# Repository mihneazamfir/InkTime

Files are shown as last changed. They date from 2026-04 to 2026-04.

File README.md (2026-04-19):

# InkTime — Open Source E-Paper Smartwatch

> Smartwatch open-source cu display e-paper, bazat pe nRF52840 SoC cu Bluetooth 5.0.

---

## Block Diagram

```
                    ┌─────────────────────────────────────────────────┐
                    │               nRF52840 (MCU)                    │
                    │          ARM Cortex-M4F @ 64MHz                 │
                    │        1MB Flash | 256KB RAM | BLE 5.0          │
                    └──┬──────────┬──────────┬──────────┬─────────────┘
                       │ SPI      │ I²C      │ GPIO     │ SWD
          ┌────────────┘          │          │          └──────────────┐
          ▼                       ▼          ▼                         ▼
  E-Paper Display         ┌──────────┐   Butoane (x3)           Debug Header
  WSH-12561 1.54"         │ I²C Bus  │   SW_UP / SW_ENT          (SWO/SWDIO
  200x200px               │ SCL/SDA  │   SW_DN                    /SWDCLK)
                          └──┬───┬───┘
                             │   │
                    ┌────────┘   └────────┐
                    ▼                     ▼
                BMA423               MAX17048
               (IMU/Step)           (Fuel Gauge)
                + DRV2605             + BQ25180
               (Haptic)              (Charger)

                    ┌──────────────────────────────────────┐
                    │          Power Management            │
                    │  USB-C ──► BQ25180 ──► AKY0106      │
                    │          (Charger)   (LiPo 400mAh)  │
                    │              │                       │
                    │              ▼                       │
                    │      RT6160AWSC (DC/DC)              │
                    │      VIN→3.3V (TP_3V3)               │
                    │      + EPD_3V3 rail separat          │
                    └──────────────────────────────────────┘
```

---

## Bill of Materials (BOM)

| Ref | Componentă | Package | Descriere | JLC Parts | Datasheet |
|-----|---|---|---|---|---|
| U1 | nRF52840-QIAA | QFN73 | MCU BLE 5.0, ARM Cortex-M4F, 1MB Flash | [C190794](https://jlcpcb.com/parts/componentSearch?isSearch=true&searchTxt=nRF52840) | [Datasheet](https://infocenter.nordicsemi.com/pdf/nRF52840_PS_v1.7.pdf) |
| U2 | RT6160AWSC | SOT-23-6 | DC/DC Step-Down 600mA, 3.3V | [C89358](https://jlcpcb.com/parts/componentSearch?isSearch=true&searchTxt=RT6160AWSC) | [Datasheet](https://www.richtek.com/assets/product_file/RT6160A/DS6160A-02.pdf) |
| U3 | MAX17048G+T10 | SOT-23-5 | LiPo Fuel Gauge, I²C 0x36 | [C112596](https://jlcpcb.com/parts/componentSearch?isSearch=true&searchTxt=MAX17048G) | [Datasheet](https://datasheets.maximintegrated.com/en/ds/MAX17048-MAX17049.pdf) |
| U4 | BMA423 | LGA-12 | IMU 3-axis Accel + Step Counter, I²C 0x18 | [C362551](https://jlcpcb.com/parts/componentSearch?isSearch=true&searchTxt=BMA423) | [Datasheet](https://www.bosch-sensortec.com/media/boschsensortec/downloads/datasheets/bst-bma423-ds000.pdf) |
| U5 | BQ25180YBGR | DSBGA-9 | LiPo Charger 350mA, I²C 0x6B | [C2682195](https://jlcpcb.com/parts/componentSearch?isSearch=true&searchTxt=BQ25180) | [Datasheet](https://www.ti.com/lit/ds/symlink/bq25180.pdf) |
| U6 | DRV2605YFRI | DSBGA-12 | Haptic Driver I²C pentru motor vibratie | [C2678581](https://jlcpcb.com/parts/componentSearch?isSearch=true&searchTxt=DRV2605) | [Datasheet](https://www.ti.com/lit/ds/symlink/drv2605.pdf) |
| DSP1 | WSH-12561 | FPC 24-pin | E-Paper Display 1.54", 200×200px, SPI | — | [Datasheet](https://www.tme.eu/Document/0ca57a8ffbcd57b5bca53252eb9d6ec3/WSH-12561.pdf) |
| BAT1 | AKY0106 | — | LiPo 3.7V 400mAh | — | [Datasheet](https://www.tme.eu/Document/b9e12bf26ad0ba929a22ab5d58f022cd/AKY0106.pdf) |
| J1 | USB Type-C 16P | — | Conector USB-C + ESD (USBLC6-2SC6Y) | — | — |
| SW1 | SW_UP | — | Buton tactil sus | — | — |
| SW2 | SW_ENT | — | Buton tactil enter | — | — |
| SW3 | SW_DN | — | Buton tactil jos | — | — |
| X2 | Crystal 32.768kHz | — | RTC crystal low-power | — | — |
| L5 | Inductor 68µH | — | E-Paper drive circuit | — | — |
| L1 | Inductor 3.9nH | — | Matching antena BLE | — | — |

---

## Hardware Functionality

### Microcontroller — nRF52840
Inima dispozitivului este **nRF52840** (Nordic Semiconductor), ARM Cortex-M4F @ 64MHz cu Bluetooth 5.0 integrat, 1MB Flash și 256KB RAM. Antena BLE este plasată pe extensia dedicată a PCB-ului (proeminența din colțul din dreapta sus), cu cutout complet sub ea, fără plane de masă și fără trasee rutate în acea zonă. Un inductor de matching de 3.9nH (L1) asigură adaptarea de impedanță a antenei.

### Display E-Paper — WSH-12561
- **Interfață:** SPI (P0.02=SCK, P0.03=MOSI, P0.04=EPD_CS, P0.05=EPD_DC) + GPIO (P0.06=EPD_RST, EPD_BUSY)
- **Rezoluție:** 200×200 px, 1.54 inch, monocrom bistabil
- **Alimentare:** EPD_3V3 — rail separat generat de DC/DC
- **Circuit drive dedicat:** bobină 68µH + diode Schottky MBR0530 + tranzistor SI1308EDL-T1-GE3
- **Consum:** ~0 µA standby (bistabil), ~26mW la refresh

### IMU — BMA423
- **Interfață:** I²C, adresă 0x18, pe bus-ul shared SDA (P0.26) / SCL (P0.27)
- **Funcții:** accelerometru 3-axis ±2–16g, pedometru hardware, wrist-tilt detection
- **IMU_INT1 / IMU_INT2** conectați la GPIO-uri nRF pentru wake-on-motion și step counter

### Fuel Gauge — MAX17048
- **Interfață:** I²C, adresă 0x36, pe bus-ul shared SDA/SCL
- **ALERT** conectat la **P0.09** pe nRF pentru notificări nivel baterie scăzut
- Algoritm ModelGauge — estimează SoC fără rezistor de sensing extern

### Battery Charger — BQ25180
- **Interfață:** I²C, adresă 0x6B, pe bus-ul shared SDA/SCL
- **PMIC_INT** conectat la **P0.11** pentru notificări charger
- Input: USB-C VBUS 5V → LiPo 3.7V, curent 350mA programabil

### DC/DC Converter — RT6160AWSC
- Step-Down sincron: VREG → 3.3V (TP_3V3), curent max 600mA, eficiență >90%
- SCL/SDA pentru ajustarea programabilă a tensiunii prin I²C
- EPD_3V3 generat ca rail separat pentru display

### Haptic Driver — DRV2605YFRI
- **Interfață:** I²C pe bus-ul shared + **HAPTIC_EN** (P0.12)
- Ieșiri JP_OP / JP_ON pentru motor vibratie LRA/ERM
- 123 efecte haptic integrate în hardware

---

## nRF52840 Pin Assignment

| Pin nRF | Net/Semnal | Componentă | Justificare |
|---|---|---|---|
| P0.00/XL1 | XL1 | Crystal 32.768kHz | RTC low-power clock |
| P0.01/XL2 | XL2 | Crystal 32.768kHz | RTC low-power clock |
| P0.02 | EPD_SCK | E-Paper SPI | SPI clock display |
| P0.03 | EPD_MOSI | E-Paper SPI | SPI data display |
| P0.04/AIN2 | EPD_CS | E-Paper | Chip select display |
| P0.05/AIN3 | EPD_DC | E-Paper | Data/Command select |
| P0.06 | EPD_RST | E-Paper | Reset hardware display |
| P0.07 | EPD_BUSY | E-Paper | Input: display ocupat |
| P0.08 | HAPTIC_EN | DRV2605 | Enable haptic driver |
| P0.09/NFC1 | ALERT | MAX17048 | Interrupt fuel gauge |
| P0.11 | PMIC_INT | BQ25180 | Interrupt charger |
| P0.12 | IMU_INT1 | BMA423 | Wake-on-motion interrupt |
| P0.13 | SW_UP | Buton sus | Input GPIO pull-up |
| P0.14 | SW_ENT | Buton enter | Input GPIO pull-up |
| P0.15 | SW_DN | Buton jos | Input GPIO pull-up |
| P0.16 | IMU_INT2 | BMA423 | Step counter interrupt |
| P0.18/RESET | RESET | — | Reset hardware MCU |
| P0.26 | SDA | I²C bus shared | Date I²C (toți senzorii) |
| P0.27 | SCL | I²C bus shared | Clock I²C |
| SWDIO | SWDIO | Debug Header | SWD programare/debug |
| SWDCLK | SWDCLK | Debug Header | SWD clock |
| SWO | SWO | Debug Header | SWD trace output |
| VBUS | VBUS | USB-C | Detecție alimentare USB |

---

## Power Budget

| Componentă | Activ | Sleep |
|---|---|---|
| nRF52840 | ~7 mA | ~2 µA (System OFF) |
| E-Paper refresh | ~7 mA (impuls ~2s) | 0 µA (bistabil) |
| BMA423 | ~150 µA | ~2 µA |
| MAX17048 | ~23 µA | ~3 µA |
| BQ25180 | ~50 µA | ~18 µA |
| DRV2605 + Motor | ~100 mA (impuls scurt) | 0 µA |
| RT6160 quiescent | ~55 µA | ~55 µA |
| **Total uz normal** | **~10–15 mA** | — |
| **Total deep sleep** | — | **~30 µA** |

**Baterie:** AKY0106 — 3.7V, 400mAh
- Uz normal (BLE activ, refresh 1/min): ~400mAh ÷ 12mA ≈ **~33 ore**
- Deep sleep (refresh rar, BLE advertising): ~400mAh ÷ 0.5mA ≈ **~33 zile**

---

## PCB Design Notes

- **Straturi:** 2 (TOP + BOTTOM), grosime PCB **1mm**
- **Plan de masă** pe ambele straturi
- **Trasee putere:** min. 0.3mm | **Trasee date:** min. 0.15mm
- **Antena nRF52840:** extensie dedicată PCB, cutout sub antenă, fără masă/trasee în zonă
- **Via stitching** între planurile de masă, în special în zona radio
- **Condensatoare decuplare 100nF** lângă pinii VDD ai fiecărui IC
- **Fără unghiuri de 90°** în trasee
- Toate componentele exclusiv pe **layer TOP**

---

## Images

### PCB 3D Render
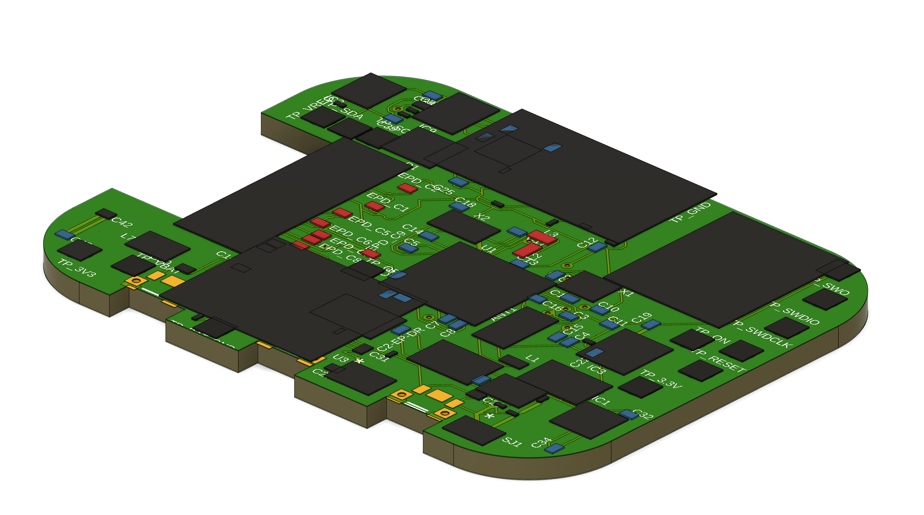
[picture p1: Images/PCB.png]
PCB 3D


### Exploded View
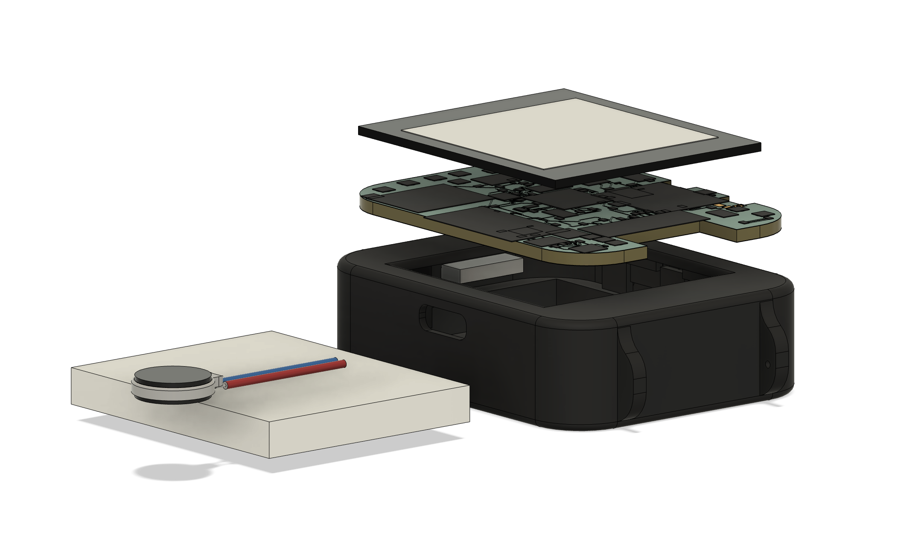
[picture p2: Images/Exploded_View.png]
Exploded View


### Device Render
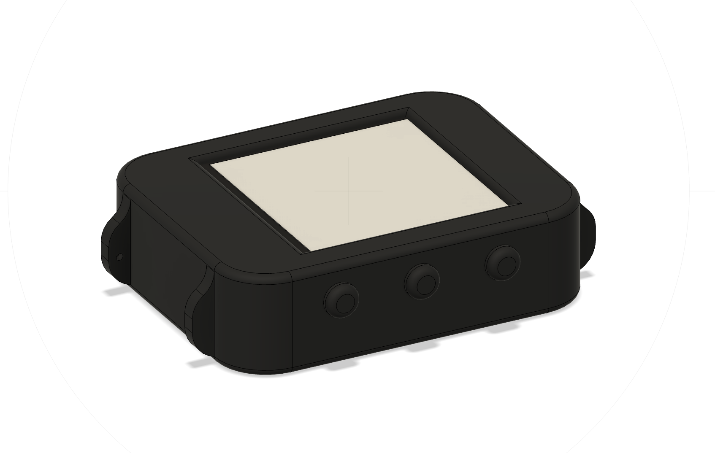
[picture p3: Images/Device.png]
Device


---

## Design Log

- **RT6160AWSC:** ales pentru eficiență la curenți mici și tensiune programabilă I²C
- **DRV2605:** 123 efecte haptic hardware fără firmware complex, suportă LRA și ERM
- **E-Paper drive circuit:** bobină 68µH + MBR0530 + SI1308EDL pentru VCOM negativ
- **Antena BLE:** extensie PCB dedicată, matching network L1=3.9nH pentru 50Ω
- **Crystal 32.768kHz:** RTC extern pentru low-power timekeeping precis
- **Bateria** conectată direct la TP_VBAT / TP_BAT_GND fără conector JST

---

## License

Distributed under the [MIT License](LICENSE).

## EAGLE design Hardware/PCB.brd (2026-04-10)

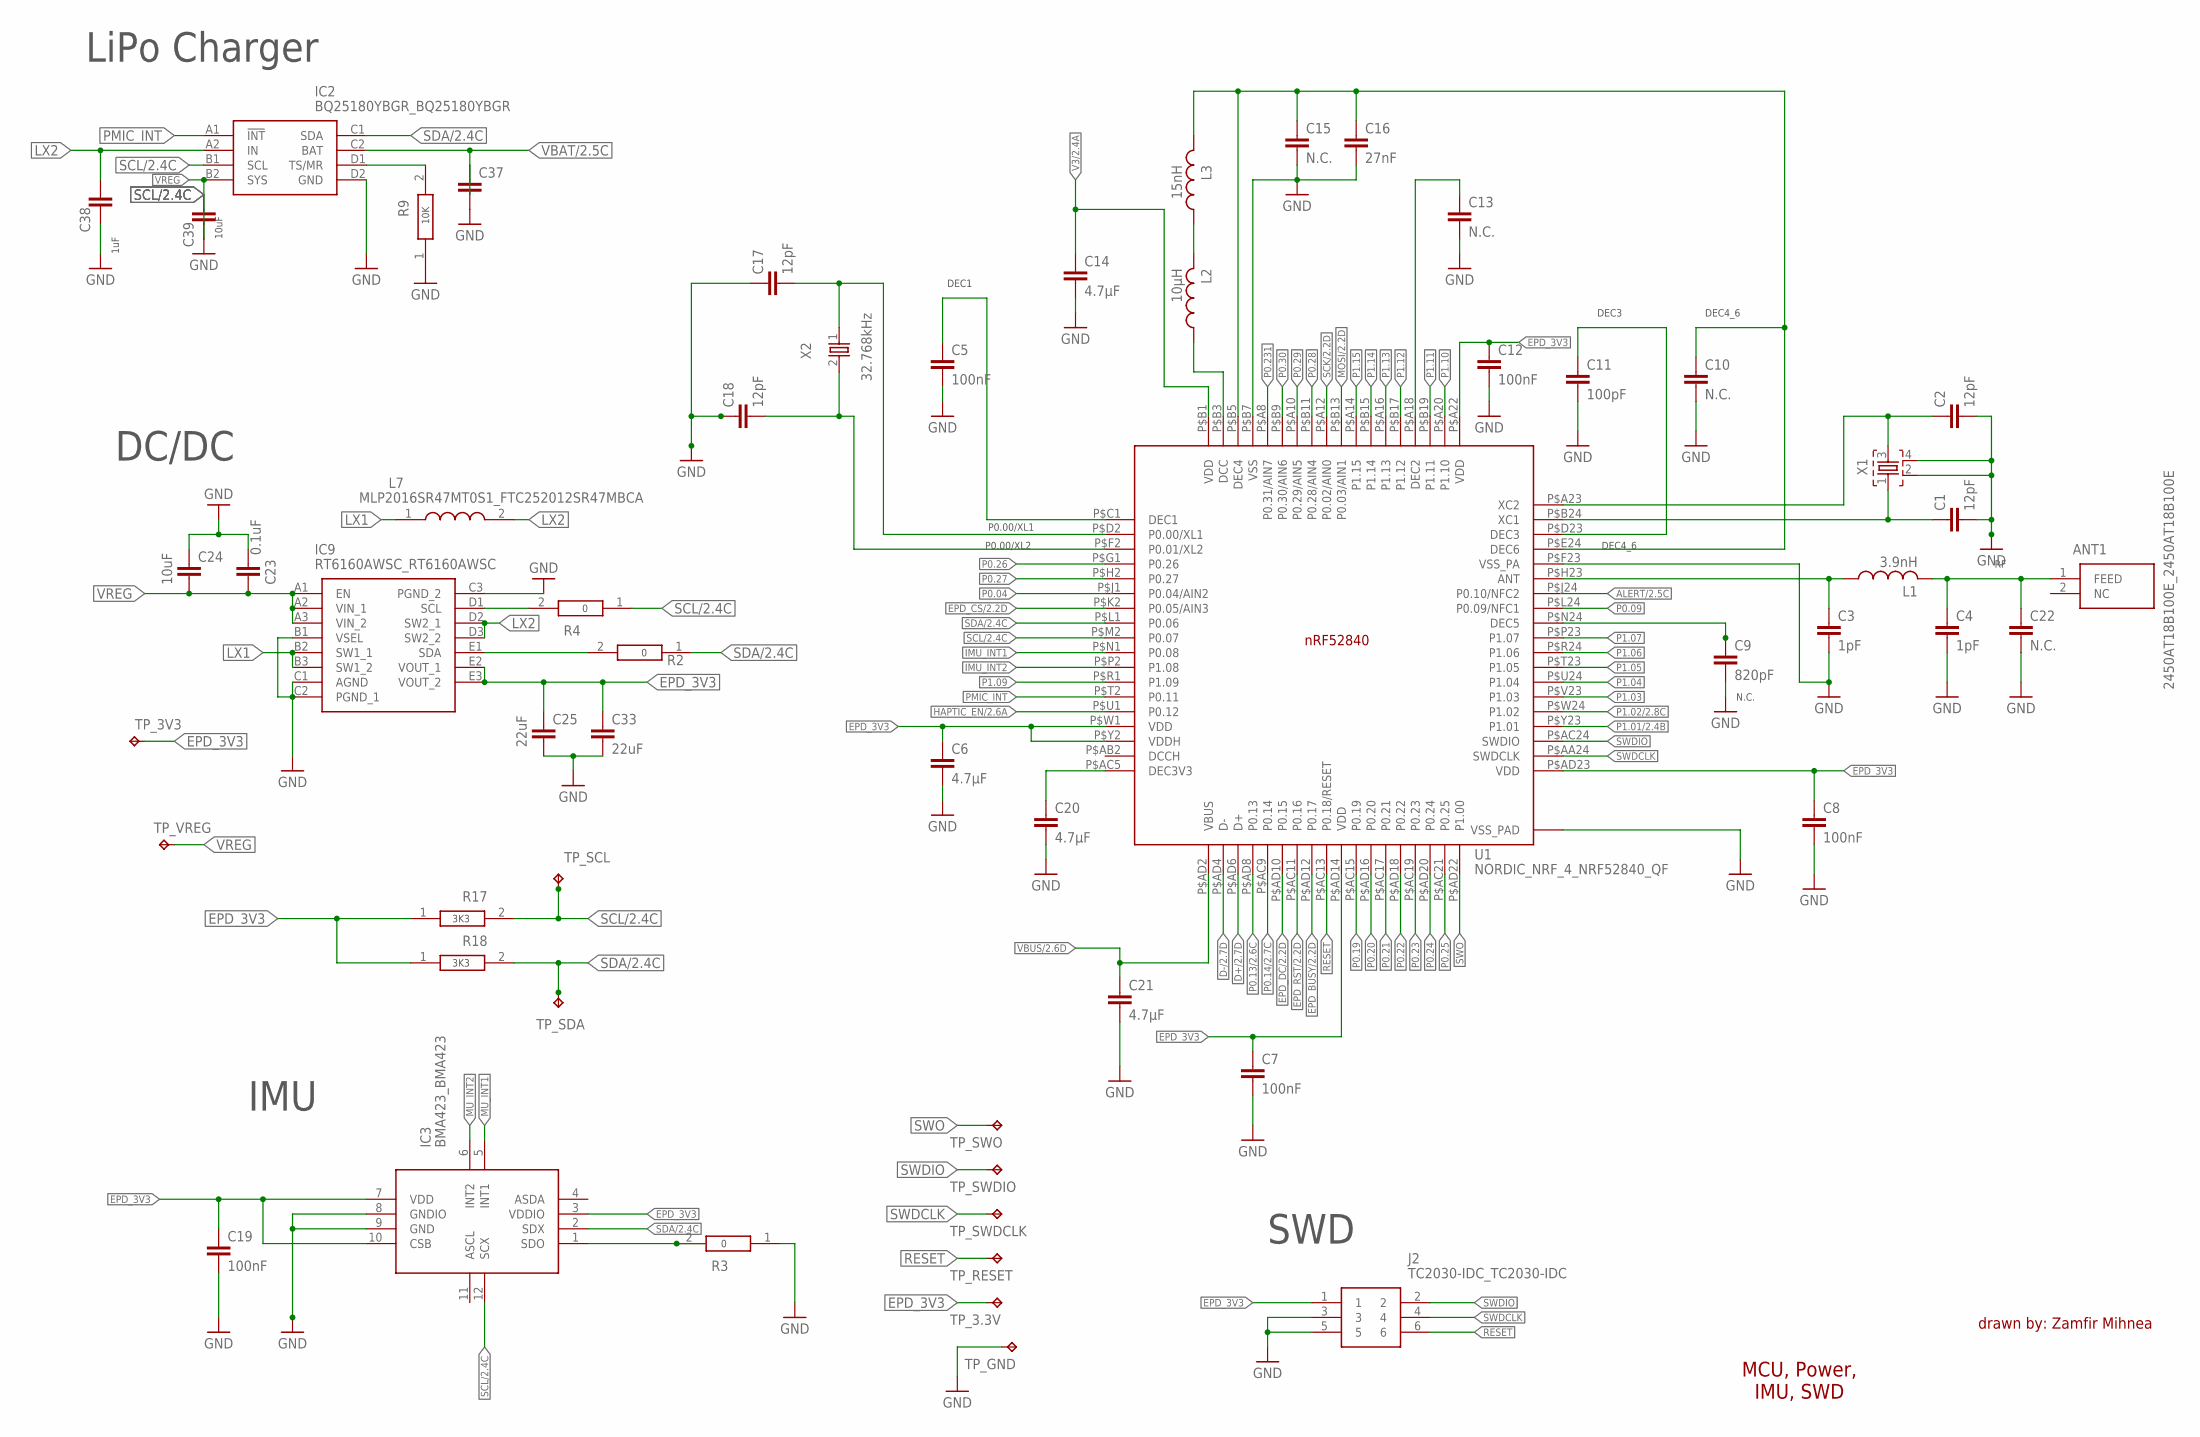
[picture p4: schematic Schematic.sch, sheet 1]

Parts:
ANT1: 2450AT18B100E_2450AT18B100E; 2450AT18B100E_ANTC3216X140N
C1, C2, C17, C18: 12pF; NORDIC_NRF_3_RESC0201_L
C3, C4: 1pF; NORDIC_NRF_3_RESC0201_L
C5, C7, C8, C12, C19: 100nF; NORDIC_NRF_3_RESC0201_L
C6, C14, C20, C21: 4.7µF; NORDIC_NRF_3_RESC0201_L
C9: 820pF; NORDIC_NRF_3_RESC0201_L
C10, C13, C15, C22: N.C.; NORDIC_NRF_3_RESC0201_L
C11: 100pF; NORDIC_NRF_3_RESC0201_L
C16: 27nF; NORDIC_NRF_3_RESC0201_L
C23: 0.1uF; NORDIC_NRF_3_RESC0201_L
C24: 10uF; NORDIC_NRF_3_RESC0201_L
C25, C33: 22uF; NORDIC_NRF_3_RESC0201_L
C37, C38, C39: NORDIC_NRF_3_CAPACITOR_0201_L; NORDIC_NRF_3_RESC0201_L
IC2: BQ25180YBGR_BQ25180YBGR; BQ25180YBGR_BGA8C40P2X4_100X155X50
IC3: BMA423_BMA423
IC9: RT6160AWSC_RT6160AWSC; RT6160AWSC_BGA15C40P3X5_140X230X60
J2: TC2030-IDC_TC2030-IDC; TC2030-IDC_TC2030IDC
L1: 3.9nH; NORDIC_NRF_2_RESC0402_L
L2: 10µH; NORDIC_NRF_2_RESC0402_L
L3: 15nH; NORDIC_NRF_2_RESC0402_L
L7: MLP2016SR47MT0S1_FTC252012SR47MBCA; MLP2016SR47MT0S1_INDC2016X100N
R2, R3, R4, R9, R17, R18: ERA-1AEB3401C_CPF0201D7K68C1; ERA-1AEB3401C_0201
TP_3.3V, TP_3V3: HECTOR_WATCH_1_TPTP20R; HECTOR_WATCH_1_TP20R
TP_GND: HECTOR_WATCH_1_TPTP20R; HECTOR_WATCH_1_TP20R
TP_RESET: HECTOR_WATCH_1_TPTP20R; HECTOR_WATCH_1_TP20R
TP_SCL: HECTOR_WATCH_1_TPTP20R; HECTOR_WATCH_1_TP20R
TP_SDA: HECTOR_WATCH_1_TPTP20R; HECTOR_WATCH_1_TP20R
TP_SWDCLK: HECTOR_WATCH_1_TPTP20R; HECTOR_WATCH_1_TP20R
TP_SWDIO: HECTOR_WATCH_1_TPTP20R; HECTOR_WATCH_1_TP20R
TP_SWO: HECTOR_WATCH_1_TPTP20R; HECTOR_WATCH_1_TP20R
TP_VREG: HECTOR_WATCH_1_TPTP20R; HECTOR_WATCH_1_TP20R
U1: NORDIC_NRF_4_NRF52840_QF; NORDIC_NRF_4_AQFN50P700X700X85_HS-74N
X1: NORDIC_NRF_XTAL_32MHZ; NORDIC_NRF_BT-XTAL_2016_N
X2: 32.768kHz; NORDIC_NRF_1_XTAL_3215_N

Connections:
GND: C3.2, C4.2, C5.2, C6.2, C7.2, C8.2, C9.2, C10.2, C11.2, C12.2, C13.2, C14.2, C15.2, C16.2, C19.2, C20.2, C21.2, C22.2, C23.1, C24.1, C25.2, C33.2, C37.2, C38.2, C39.1, C39.2, IC2.B2 (SYS), IC2.D2 (GND), IC9.B1 (VSEL), IC9.C1 (AGND), IC9.C2 (PGND_1), IC9.C3 (PGND_2), J2.3, J2.5, R3.1, R9.1, TP_GND.TP, U1.P$74 (VSS_PAD), U1.P$75 (VSS_PAD), U1.P$76 (VSS_PAD), U1.P$77 (VSS_PAD), U1.P$78 (VSS_PAD), U1.P$79 (VSS_PAD), U1.P$80 (VSS_PAD), U1.P$81 (VSS_PAD), U1.P$82 (VSS_PAD), U1.P$83 (VSS_PAD), U1.P$84 (VSS_PAD), U1.P$85 (VSS_PAD), U1.P$86 (VSS_PAD), U1.P$87 (VSS_PAD), U1.P$88 (VSS_PAD), U1.P$89 (VSS_PAD), U1.P$90 (VSS_PAD), U1.P$B7 (VSS), U1.P$F23 (VSS_PA); also elsewhere on the board
unnamed: IC2.D1 (TS/MR), R9.2
unnamed: C38.1, IC2.A2 (IN)
unnamed: C37.1, IC2.C2 (BAT)
unnamed: C23.2, C24.2, IC9.A1 (EN), IC9.A2 (VIN_1), IC9.A3 (VIN_2)
unnamed: IC9.B2 (SW1_1), IC9.B3 (SW1_2)
unnamed: IC9.D1 (SCL), R4.2
unnamed: R17.1, R18.1
unnamed: IC9.D2 (SW2_1), IC9.D3 (SW2_2)
unnamed: C25.1, C33.1, IC9.E2 (VOUT_1), IC9.E3 (VOUT_2)
unnamed: IC9.E1 (SDA), R2.2
unnamed: C19.1, IC3.7 (VDD), IC3.10 (CSB)
unnamed: IC3.8 (GNDIO), IC3.9 (GND)
unnamed: IC3.1 (SDO), R3.2
unnamed: C7.1, U1.P$AD14 (VDD)
unnamed: C21.1, U1.P$AD2 (VBUS)
unnamed: C8.1, U1.P$AD23 (VDD)
unnamed: C3.1, L1.1, U1.P$H23 (ANT)
unnamed: ANT1.1 (FEED), C4.1, C22.1, L1.2
unnamed: C10.1, C15.1, C16.1, L3.2, U1.P$B5 (DEC4), U1.P$E24 (DEC6)
unnamed: C11.1, U1.P$D23 (DEC3)
unnamed: C1.1, U1.P$B24 (XC1), X1.1
unnamed: C2.1, U1.P$A23 (XC2), X1.3
unnamed: C1.2, C2.2, X1.2, X1.4
unnamed: C12.1, U1.P$A22 (VDD)
unnamed: C13.1, U1.P$A18 (DEC2)
unnamed: L2.2, L3.1
unnamed: L2.1, U1.P$B3 (DCC)
unnamed: C20.1, U1.P$AC5 (DEC3V3)
unnamed: C6.1, U1.P$W1 (VDD), U1.P$Y2 (VDDH)
unnamed: C14.1, U1.P$B1 (VDD)
unnamed: C5.1, U1.P$C1 (DEC1)
unnamed: C17.2, U1.P$D2 (P0.00/XL1), X2.1
unnamed: C18.2, U1.P$F2 (P0.01/XL2), X2.2
SDA/2.4C: IC2.C1 (SDA)

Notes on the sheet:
LiPo Charger
10K
DC/DC
3K3
10uF
1uF
IMU
N.C.
DEC3
DEC4_6
DEC1
P0.00/XL1
P0.00/XL2
drawn by: Zamfir Mihnea
MCU, Power, IMU, SWD
SWD

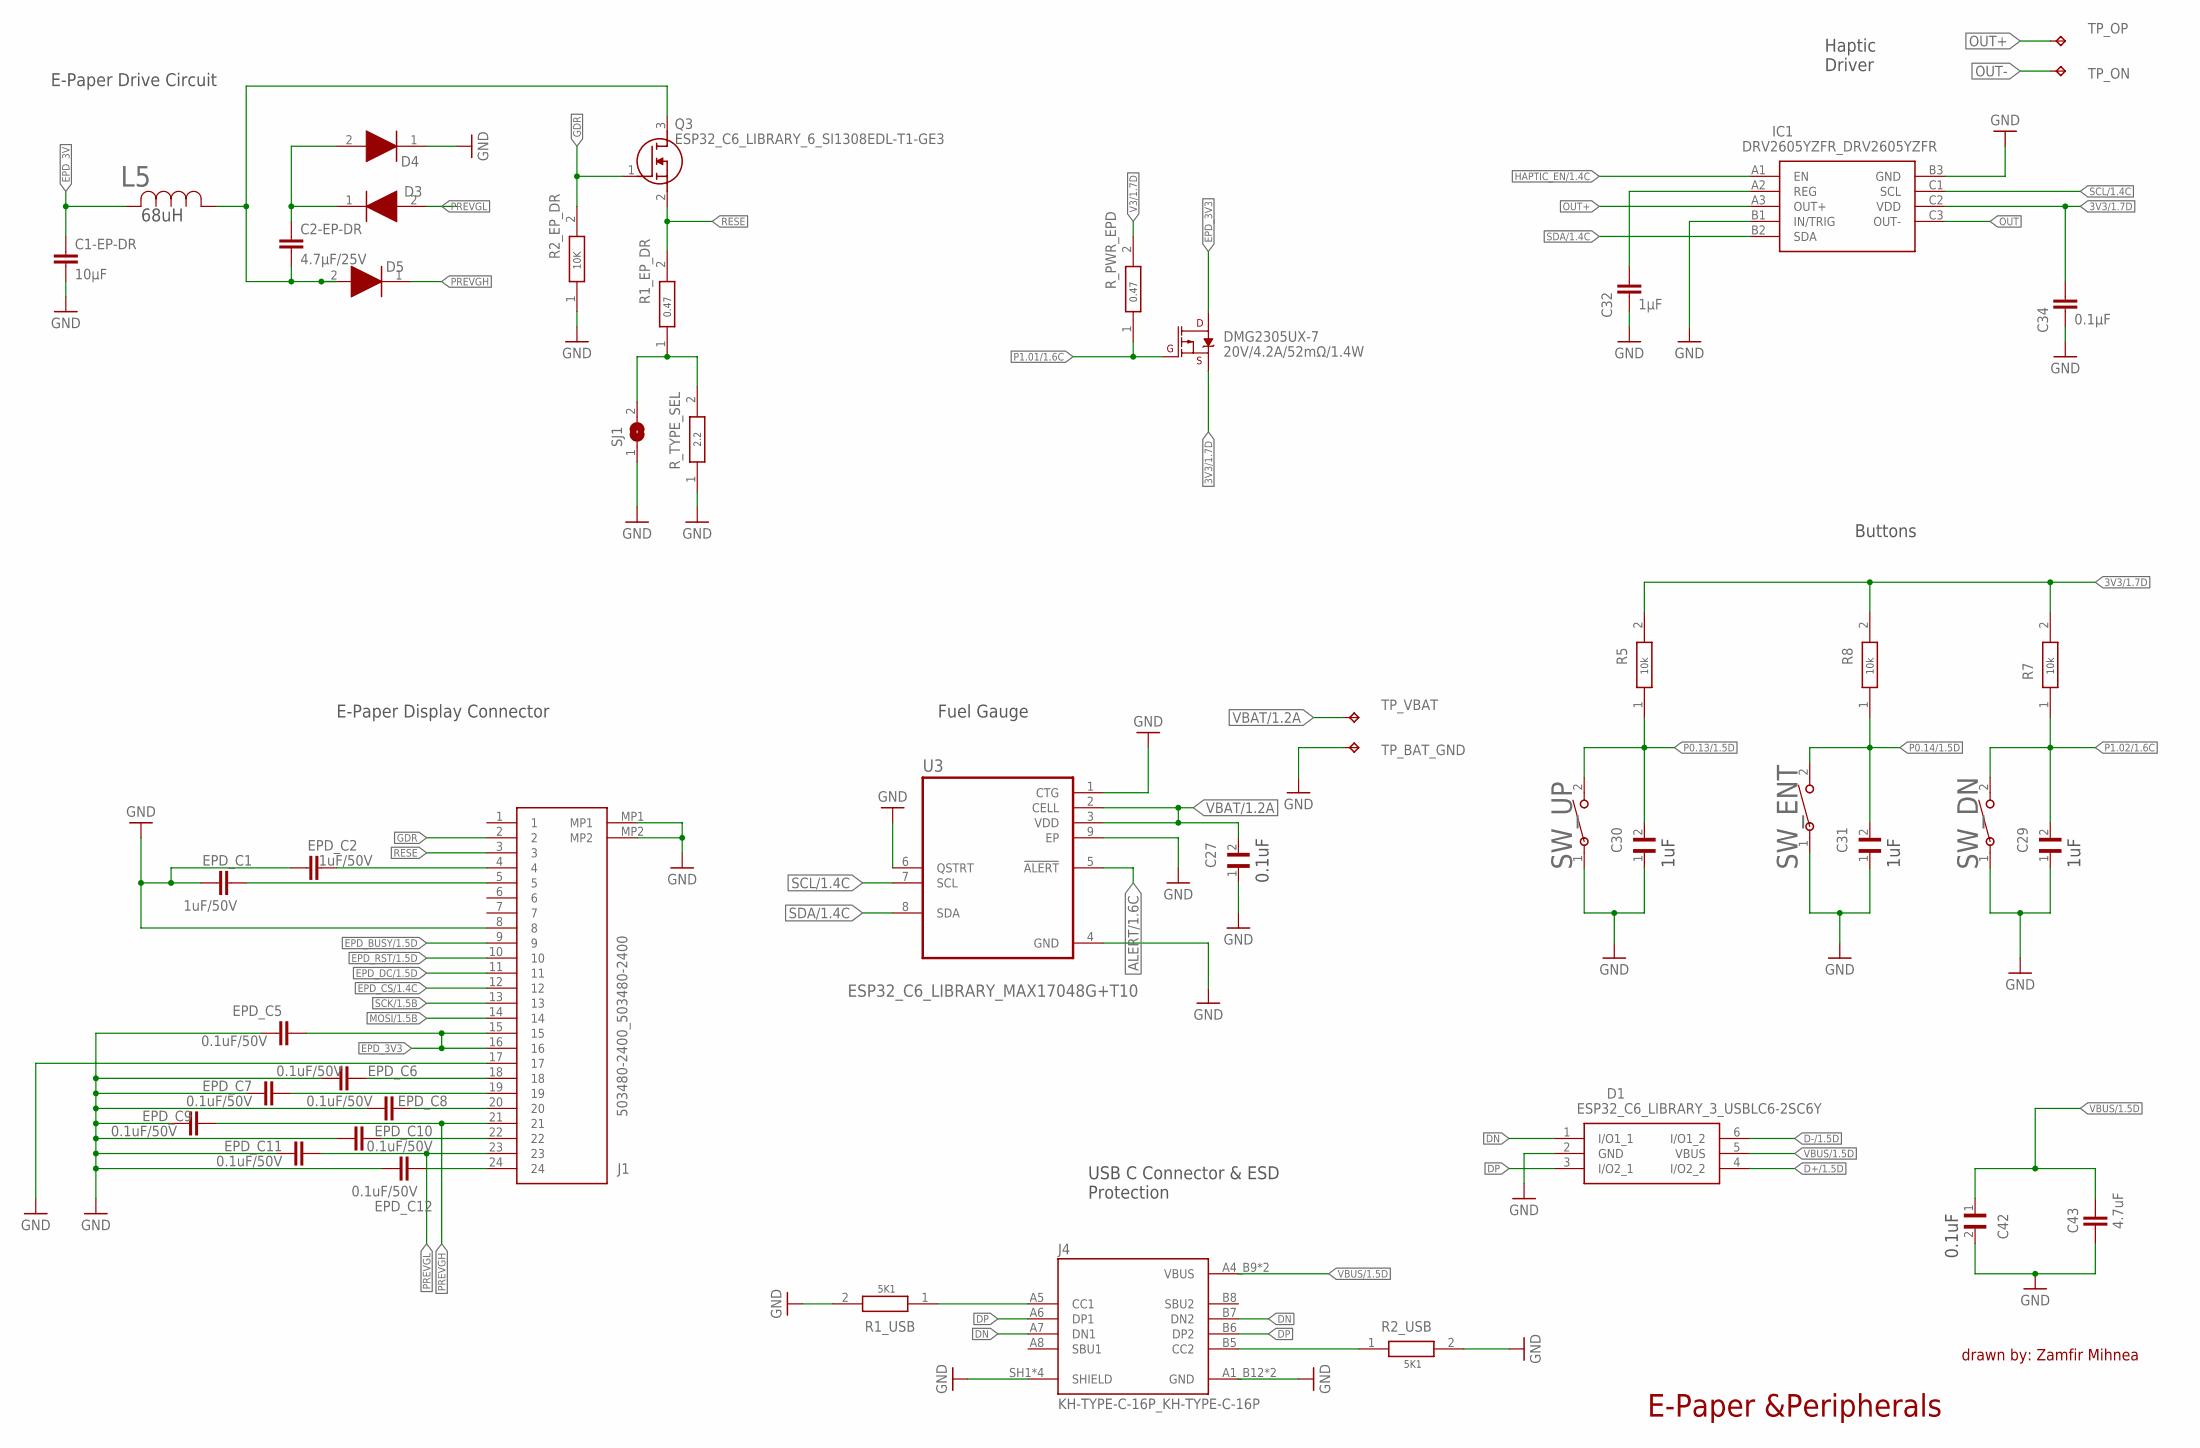
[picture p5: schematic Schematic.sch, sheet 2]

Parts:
C1-EP-DR: 10µF; NORDIC_NRF_3_RESC0201_L
C2-EP-DR: 4.7µF/25V; NORDIC_NRF_3_RESC0201_L
C27, C29, C30, C31, C42: GRM011R60J152KE01L_2_GRM011R60J152KE01L; GRM011R60J152KE01L_2_CAPC0201X13N
C32: 1µF; NORDIC_NRF_3_RESC0201_L
C34: 0.1µF; NORDIC_NRF_3_RESC0201_L
C43: 4.7uF; NORDIC_NRF_3_RESC0201_L
D1: ESP32_C6_LIBRARY_3_USBLC6-2SC6Y; ESP32_C6_LIBRARY_3_SOT95P280X145-6N
D3, D4, D5: ESP32_C6_LIBRARY_5_MBR0530; ESP32_C6_LIBRARY_5_SOD3716X135N
DMG2305UX-7: 20V/4.2A/52mΩ/1.4W; ESP32_C6_LIBRARY_4_ESP32_C6_LIBRARY_4_ESP32_C6_LIBRARY_4_ES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
EPD_C1, EPD_C2: 1uF/50V; NORDIC_NRF_3_RESC0201_L
EPD_C5, EPD_C6, EPD_C7, EPD_C8, EPD_C9, EPD_C10, EPD_C11, EPD_C12: 0.1uF/50V; NORDIC_NRF_3_RESC0201_L
IC1: DRV2605YZFR_DRV2605YZFR; DRV2605YZFR_BGA9C50P3X3_144X144X62
J1: 503480-2400_503480-2400; 503480-2400_5034802400
J4: KH-TYPE-C-16P_KH-TYPE-C-16P; KH-TYPE-C-16P_KINGHELM_KH-TYPE-C-16P
L5: 68uH; ESP32_C6_LIBRARY_2_IND_4828-WE-TPC_WRE
Q3: ESP32_C6_LIBRARY_6_SI1308EDL-T1-GE3; ESP32_C6_LIBRARY_6_SOT65P210X110-3N
R1_EP_DR, R1_USB, R2_EP_DR, R2_USB, R5, R7, R8: ERA-1AEB3401C_CPF0201D7K68C1; ERA-1AEB3401C_0201
R_PWR_EPD: ERA-1AEB3401C_CPF0201D7K68C1; ERA-1AEB3401C_0201
R_TYPE_SEL: ERA-1AEB3401C_CPF0201D7K68C1; ERA-1AEB3401C_0201
SJ1: ESP32_C6_LIBRARY_7_JUMPER_SJ
SW_DN: 2025-10-22_07-23-44_LIBRARY_EVP-AKE31ASW_EVP-AKE3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; 2025-10-22_07-23-44_LIBRARY_SW_EVP-AKE31A_PAN
SW_ENT: 2025-10-22_07-23-44_LIBRARY_EVP-AKE31ASW_EVP-AKE3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; 2025-10-22_07-23-44_LIBRARY_SW_EVP-AKE31A_PAN
SW_UP: 2025-10-22_07-23-44_LIBRARY_EVP-AKE31ASW_EVP-AKE3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; 2025-10-22_07-23-44_LIBRARY_SW_EVP-AKE31A_PAN
TP_BAT_GND: HECTOR_WATCH_1_TPTP20R; HECTOR_WATCH_1_TP20R
TP_ON: HECTOR_WATCH_1_TPTP20R; HECTOR_WATCH_1_TP20R
TP_OP: HECTOR_WATCH_1_TPTP20R; HECTOR_WATCH_1_TP20R
TP_VBAT: HECTOR_WATCH_1_TPTP20R; HECTOR_WATCH_1_TP20R
U3: ESP32_C6_LIBRARY_MAX17048G+T10; ESP32_C6_LIBRARY_SON50P200X200X80-9N

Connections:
GND: C1-EP-DR.2, C27.1, C29.1, C30.1, C31.1, C32.2, C34.2, D1.2 (GND), D4.1 (K), EPD_C1.1, EPD_C2.1, EPD_C5.1, EPD_C6.1, EPD_C7.1, EPD_C8.1, EPD_C9.1, EPD_C10.1, EPD_C11.1, EPD_C12.1, IC1.B1 (IN/TRIG), IC1.B3 (GND), J1.8, J1.17, J1.MP1, J1.MP2, J4.A1_B12 (GND), J4.A12_B1 (GND), J4.SH1 (SHIELD), J4.SH2 (SHIELD), J4.SH3 (SHIELD), J4.SH4 (SHIELD), R1_USB.2, R2_EP_DR.1, R2_USB.2, R_TYPE_SEL.1, SJ1.1, SW_DN.1, SW_ENT.1, SW_UP.1, TP_BAT_GND.TP, U3.1 (CTG), U3.4 (GND), U3.6 (QSTRT), U3.9 (EP); also elsewhere on the board
GND1: R1_EP_DR.1, R_TYPE_SEL.2, SJ1.2
GND2: C29.2, R7.1, SW_DN.2
GND3: C31.2, R8.1, SW_ENT.2
GND4: C30.2, R5.1, SW_UP.2
unnamed: C1-EP-DR.1, L5.2
unnamed: C2-EP-DR.2, D5.2 (A), L5.1, Q3.3 (D)
unnamed: C2-EP-DR.1, D3.1 (K), D4.2 (A)
unnamed: Q3.1 (G), R2_EP_DR.2
unnamed: Q3.2 (S), R1_EP_DR.2
unnamed: DMG2305UX-7.1 (G), R_PWR_EPD.1
unnamed: C32.1, IC1.A2 (REG)
unnamed: C34.1, IC1.C2 (VDD)
unnamed: R5.2, R7.2, R8.2
unnamed: C27.2, U3.2 (CELL), U3.3 (VDD)
unnamed: EPD_C12.2, J1.24
unnamed: EPD_C2.2, J1.4
unnamed: EPD_C1.2, J1.5
unnamed: EPD_C5.2, J1.15, J1.16
unnamed: EPD_C11.2, J1.23
unnamed: EPD_C10.2, J1.22
unnamed: EPD_C9.2, J1.21
unnamed: EPD_C8.2, J1.20
unnamed: EPD_C7.2, J1.19
unnamed: EPD_C6.2, J1.18
unnamed: J4.A4_B9 (VBUS), J4.A9_B4 (VBUS)
unnamed: J4.B5 (CC2), R2_USB.1
unnamed: J4.A5 (CC1), R1_USB.1
unnamed: C42.2, C43.1
unnamed: C42.1, C43.2

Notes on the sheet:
E-Paper Drive Circuit
10K
0.47
2.2
68uH
Haptic Driver
Buttons
10k
1uF
Fuel Gauge
0.1uF
E-Paper Display Connector
USB C Connector & ESD Protection
5K1
E-Paper &Peripherals
drawn by: Zamfir Mihnea

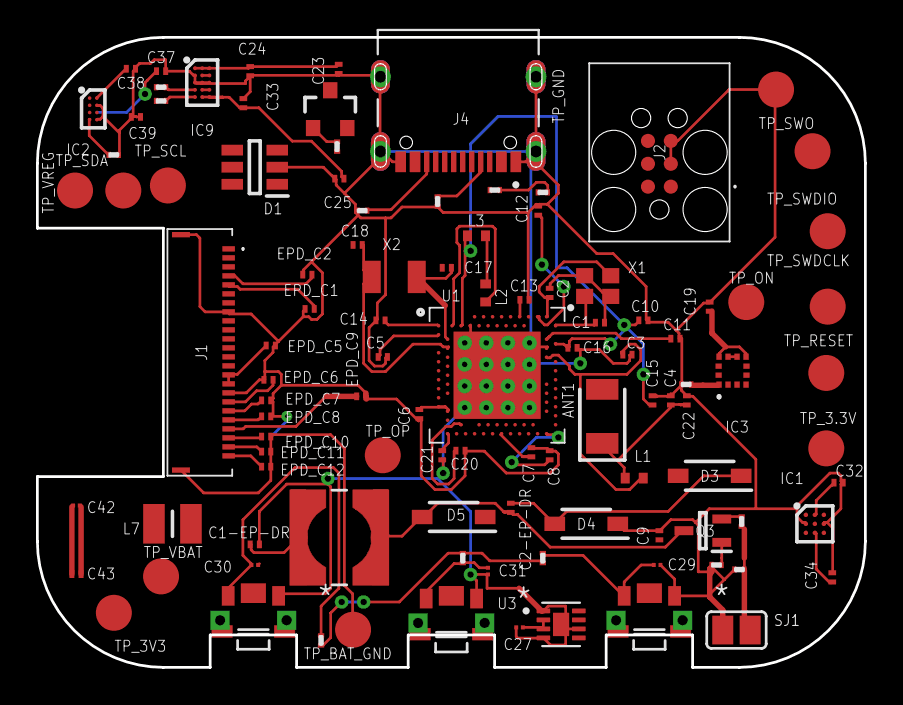
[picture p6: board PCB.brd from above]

Board: 2 copper layers, 46.0 x 35.0 mm, 105 parts (0 on the bottom side), 63 nets.

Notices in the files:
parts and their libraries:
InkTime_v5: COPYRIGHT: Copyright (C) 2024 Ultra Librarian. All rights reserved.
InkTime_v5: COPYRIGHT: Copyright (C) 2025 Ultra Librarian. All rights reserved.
